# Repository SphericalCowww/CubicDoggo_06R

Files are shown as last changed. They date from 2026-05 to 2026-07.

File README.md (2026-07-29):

# Cubic Doggo 06R: Homemade 12-DOF 4-Legged Robot Recipe, With IMU

Cubic Doggo 06R High Mobility is an upgrade from the base <a href="https://github.com/SphericalCowww/CubicDoggo">Cubic Doggo</a>. It receives several mechanical improvements and applies an IMU for balance. The upgraded CADv2 files can be found in <a href="https://github.com/SphericalCowww/CubicDoggo_06R/tree/main/src/my_robot_description/mesh/CADv2">GitHub directory</a>/<a href="https://www.printables.com/model/1790901-cubic-doggo-06r-high-mobility">Printables</a>.

Demos: wobbly IMU (<a href="https://www.reddit.com/r/robotics/comments/1u1iql9/cubic_doggo_update_wobbly_imu/">Reddit</a>/<a href="https://www.reddit.com/r/ROS/comments/1u1j9yf/cubic_doggo_update_wobbly_imu/">Reddit</a>), standing IMU tunning (<a href="https://www.reddit.com/r/robotics/comments/1ugo3kj/cubic_doggo_update_returning_to_basics_after_all/">Reddit</a>/<a href="https://www.reddit.com/r/ROS/comments/1ugw66z/cubic_doggo_update_returning_to_basics_after_all/">Reddit</a>), leg lifting (<a href="https://www.reddit.com/r/robotics/comments/1ux2n51/cubic_doggo_update_what_does_it_takes_to_lift_its/">Reddit</a>), walking with IMU (<a href="https://www.reddit.com/r/robotics/comments/1v69uqf/cubic_doggo_upgrade_walking_with_imu/">Reddit</a>)



* Left: the following shows the high-lift mode available after all the mechanical improvements. The black notepad in the center is 1cm in height, and the robot is able to land on it with all 4 of its feet. However, you can see that landing off the notepad gives a rather high impact load to the landing leg.
* Right: walking with IMU balance correction based on BNO055, controlled using PID (technically on kP to avoid diverging oscillation). It's walking down from the notepad because the current IMU system cannot support the high-lift mode. Although the effect is not obvious, the robot is constantly trying to balance itself after standing up and during walking.
* Note also that a servo (or servos) from the robot's back-right leg is likely damaged/performance-reduced from dimension collisions during the test using the spring/compliant feet (see <a href="https://www.reddit.com/r/robotics/comments/1ux2n51/cubic_doggo_update_what_does_it_takes_to_lift_its/">Reddit</a>) 

## Ingredients

### CAD Improvements

1. Support on the 1st servos on both sides
2. Support on the 3rd servos. These joints always broke first
3. Spring-like feet (<a href="https://www.reddit.com/r/robotics/comments/1un8jxc/3dprinted_compliant_robot_legs/">Reddit</a>)
4. Smaller feet tip. Swinging less mass should cause less wobbling
5. Start using PLA+

Also updated the initial leg position such that the center of mass is optimized at trotting in place.

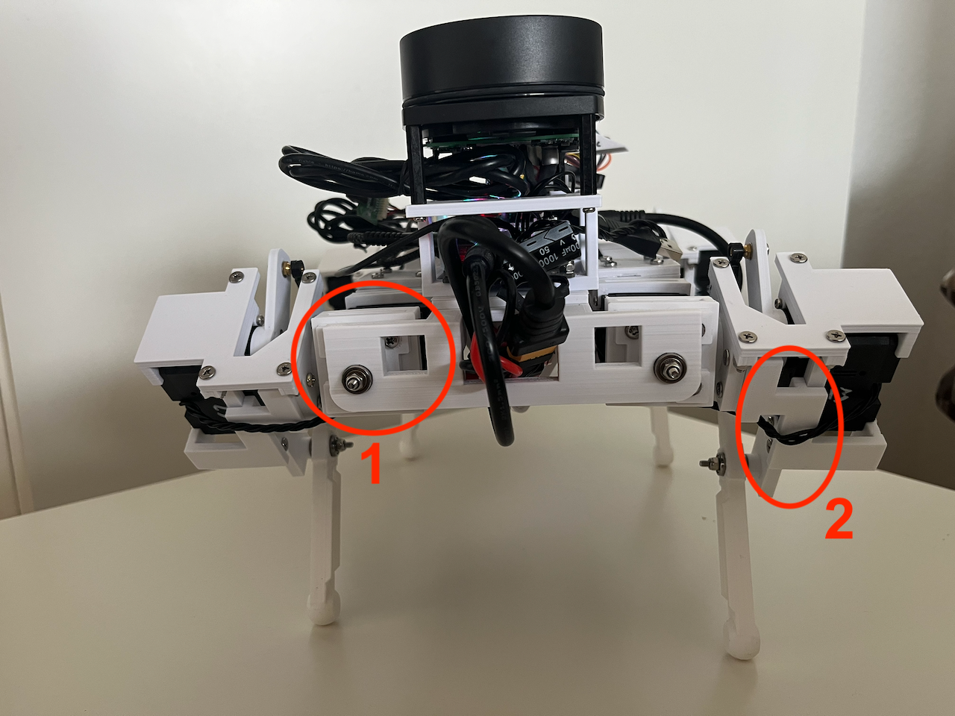
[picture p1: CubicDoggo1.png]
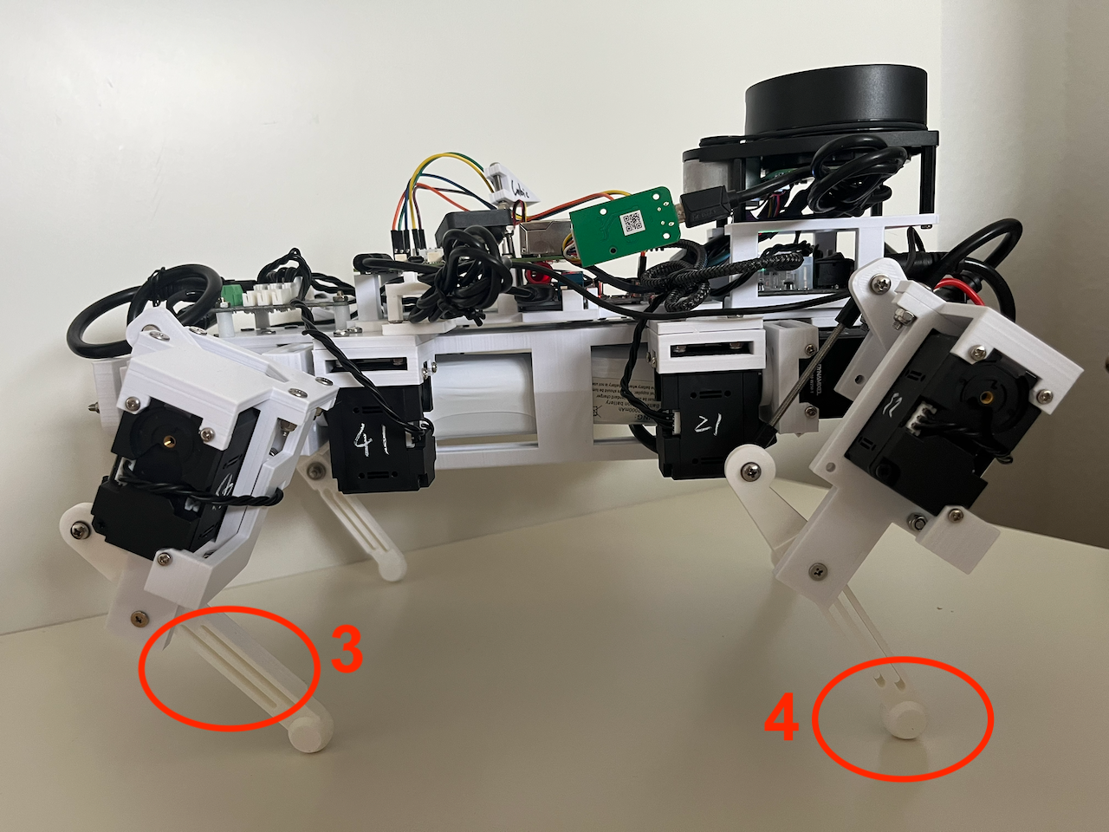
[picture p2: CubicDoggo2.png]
  

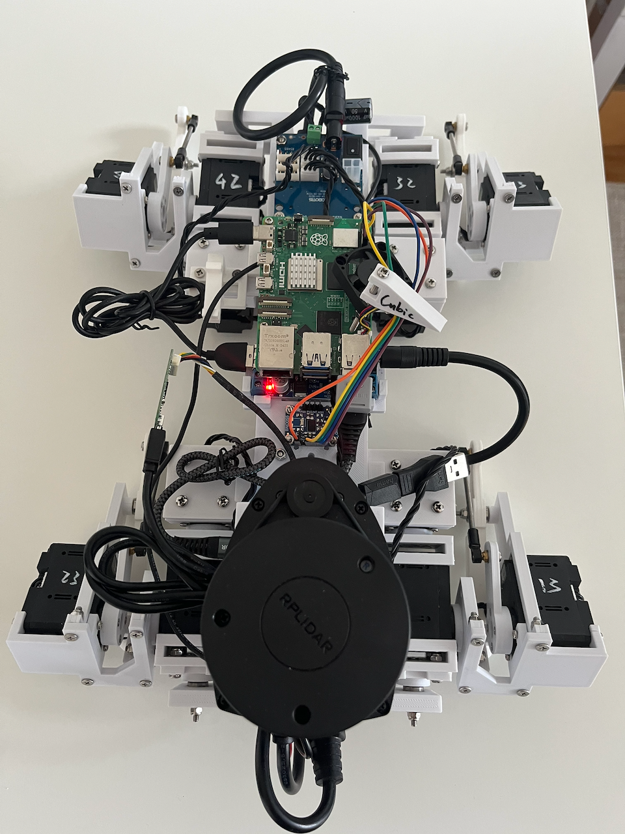
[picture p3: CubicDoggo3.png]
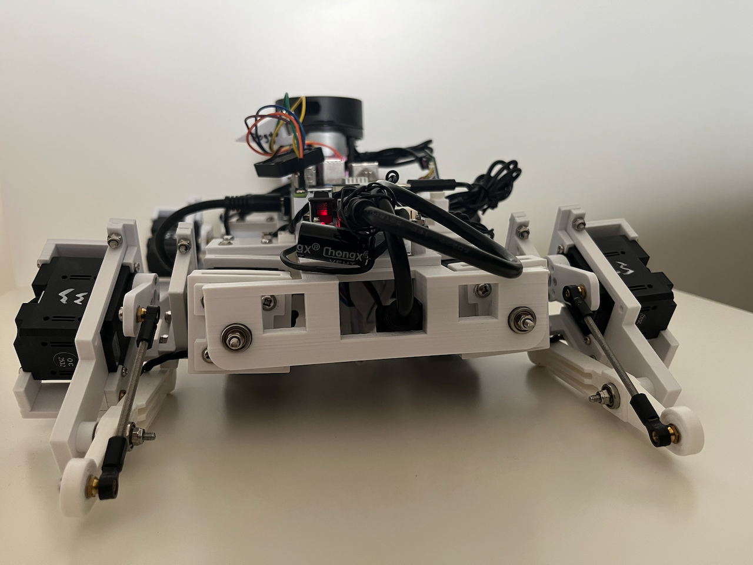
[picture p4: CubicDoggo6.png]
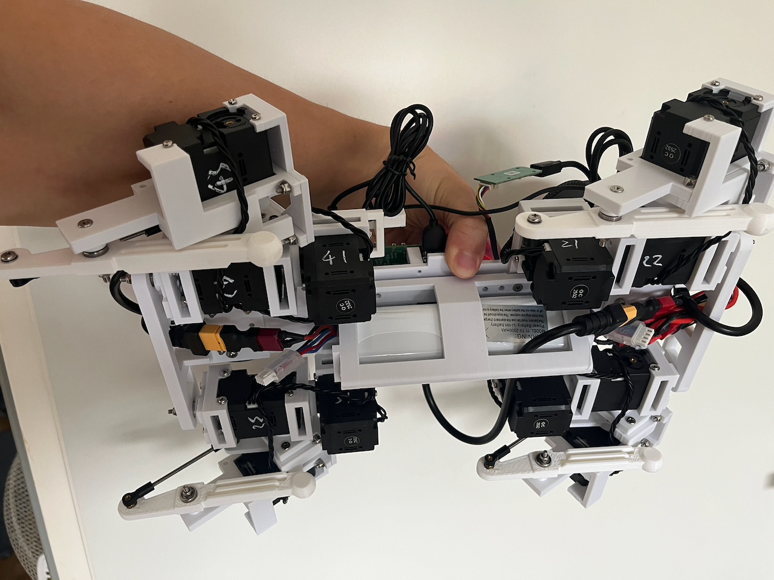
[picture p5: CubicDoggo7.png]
   

### IMU Hardware 

| device | models | count | specification |
| - | - | - | - |
| IMU | Adafruit <a href="https://www.adafruit.com/product/2472?srsltid=AfmBOopFaOJasrKIi1FkizYHaVd5CtUsoR6xX3qAALgU8sYoLY70Q55M">BNO055 [ADA2472]</a> | 1 | in-system Kalman Filter, but rate capped at 100 Hz |
| IMU | <a href="https://de.aliexpress.com/item/1005009869623539.html">BMI088</a> | 1 | rate available at 200 Hz after ROS2 ``imu_filter_madgwick`` |
| IMU | <a href="https://de.aliexpress.com/item/1005010500159119.html">ICM-42688-P</a> | 1 | rate available at 200-400 Hz after ROS2 ``imu_filter_madgwick`` |

So far, only BNO055 is tested. Future incorporation with BMI088 or ICM-42688-P will likely improve the IMU performance: the current PID oscillation is potentially caused by delayed IMU correction at the BNO055 readout rate set of 50 Hz.

## Testing IMU/Peripherals

### Testing IMU BN055

Following <a href="https://cdn-learn.adafruit.com/downloads/pdf/bno055-absolute-orientation-sensor-with-raspberry-pi-and-beaglebone-black.pdf">link</a>. It's a bit outdated, so do change up a bit and actually connect via I2C instead for RaspPi > 3:

  * Vin to 1
  * GND to 9 
  * SDA to 3
  * SCL to 5
  * RST to 11



Then do:

    sudo apt update && sudo apt install -y i2c-tools gpiod libgpiod-dev
    sudo gpiodetect
    sudo gpioset gpiochip4 17=1                                         # enable reset pin
    sudo i2cdetect -y 1                                                 # if 28 lights up, it's alive

    sudo usermod -aG i2c $USER
    sudo usermod -aG dialout $USER
    sudo reboot
    i2cdetect -y 1

To test BNO055 without ROS:
    
    sudo apt install -y python3-venv python3-pip python3-lgpio
    cd CubicDoggo_06R/python_test_scripts
    python3 -m venv env
    source env/bin/activate
    pip install adafruit-circuitpython-bno055 rpi-lgpio
    python bno_test.py
    
To test BNO055 with ROS:

    cd CubicDoggo_06R
    colcon build
    source install/setup.bash
    ros2 run my_robot_peripheral imu_bno055_node
    # on another terminal
    ros2 topic echo /imu/euler              # show IMU content
    ros2 topic hz /imu/euler                # show IMU read speed

### Testing the joystick controller:

    ls /dev/input/js*
    # output: /dev/input/js0
    # otherwise do: sudo jstest /dev/input/js0
    ros2 run joy joy_enumerate_devices
    # if no device found
    sudo usermod -aG input $USER
    sudo reboot

    cd CubicDoggo_06R
    colcon build
    source install/setup.bash
    ros2 run joy joy_node
    # on another terminal
    ros2 run my_robot_controller cubic_doggo_joy_control
    # on yet another terminal
    ros2 node info /cubic_doggo_joy_control    
    ros2 topic info /joy --verbose
    ros2 topic echo /joy

### Checking RaspPi power

    for d in /sys/class/hwmon/hwmon*; do echo -n "$d: "; cat "$d/name"; done   # find the correct path for power alarm
    # update /home/cubicdoggo/Documents/CubicDoggo_06R/src/my_robot_bringup/launch/cubic_doggo.with_lifecycle.launch.py
    echo timer | sudo tee /sys/class/leds/ACT/trigger                          # trigger LED first
    sudo chmod -R 777 /sys/class/leds/ACT/                                     # enable LED to indicate battery condition
    sudo chmod -R 777 /sys/class/hwmon/hwmon*/                                 # enable reading of power alarm/voltage
    # test the node 
    echo 0 > /tmp/fake_alarm                                                   # create a fake alarm by
    ros2 run my_robot_peripheral rasp_pi_peripheral_node --ros-args -p alarm_path:=/tmp/fake_alarm
    echo 1 > /tmp/fake_alarm                                                   # create a fake alarm by

## Running the robot

Follow this <a href="https://github.com/SphericalCowww/CubicDoggo/tree/main#running-a-single-servo-on-ros2">GitHub section</a> to set up the servos.

### Assembly and Launching URDF

Run the following to view the moving parts:

    cd CubicDoggo_06R
    colcon build
    source install/setup.bash
    ros2 launch my_robot_description cubic_doggo.rviz.launch.xacro.py

Notice that the placement of the first servo is different between the front and back legs.

### Launching with commands

Under: ``CubicDoggo_06R/src/my_robot_description/urdf/cubic_doggo.ros2_control.xacro``

   * use ``<plugin>mock_components/GenericSystem</plugin>`` if just want rViz
   * use ``<<plugin>cubic_doggo_namespace/HardwareInterfaceU2D2_cubic_doggo</plugin>`` if want to control hardware

Under: ``CubicDoggo_06R/src/my_robot_bringup/launch/cubic_doggo.with_lifecycle.launch.py``

   * choose from:
     * ``executable="cubic_doggo_lifecycle"`` for no IMU
     * ``executable="cubic_doggo_lifecycle_imuNode"`` for standing with an IMU node
     * ``executable="cubic_doggo_lifecycle_imuController"`` for standing with an IMU controller using ``ros2_control``
     * ``executable="cubic_doggo_lifecycle_imuController_walking"`` for standing/walking with an IMU controller using ``ros2_control``
     * ``executable="cubic_doggo_lifecycle_imuController_walkingToggle"`` to start with no IMU, but can toggle on for standing/walking with an IMU controller using ``ros2_control``

   * comment out ``imu_node`` unless using ``executable="cubic_doggo_lifecycle_imuNode"``
   * comment out ``rviz_node`` if don't want rViz to show
   * comment out ``joy_driver_node`` and ``joy_controller_node`` if don't want the joystick controller
   * comment out ``peripheral_node`` if don't want warning from low power

Start the robot (skip launching rviz_node, joy_driver_node, or joy_controller_node if needed):

    cd CubicDoggo_06R
    colcon build
    source install/setup.bash
    # comment in rvis node in CubicDoggo_06R/src/my_robot_bringup/launch/cubic_doggo.with_lifecycle.launch.py
    ros2 launch my_robot_bringup cubic_doggo.with_lifecycle.launch.py
    # on another terminal
    ros2 topic pub -1 /leg_set_named example_interfaces/msg/String "{data: "rest"}"
    ros2 topic pub -1 /leg_set_named example_interfaces/msg/String "{data: "stand"}"
    ros2 topic pub -1 /leg_set_named example_interfaces/msg/String "{data: "sit"}"
    ros2 topic pub -1 /leg_set_named example_interfaces/msg/String "{data: "bow"}"
    ros2 topic pub -1 /leg_set_joint example_interfaces/msg/Float64MultiArray "{data: [0, 3.14, 3.14, 3.54]}"
    ros2 topic pub -1 /leg_set_pose my_robot_interface/msg/CubicDoggoLegPoseTarget "{leg_index: 0, x: -0.092, y: 0.053, z: 0.135}" 
    ros2 service call /leg_walk_toggle std_srvs/srv/SetBool "{data: true}"
    ros2 service call /leg_walk_toggle std_srvs/srv/SetBool "{data: false}"

Check out all the gait/IMU options under ``CubicDoggo_06R/src/my_robot_commander/src/cubic_doggo_lifecycle_imuController_walking.cpp``:

    # rclcpp::get_logger("").set_level(rclcpp::Logger::Level::Warn);        // for silencing output
    ...
    # aw_strat.i_max =  0.05;
    # aw_strat.i_min = -0.05;
    # double kP = 0.0016, kI = 0.0001, kD = 0.0;     // NOTE: PID
    # double corr_v_thres = 3.0, corr_d_thres = 1.0;              // threshold on pitch/roll and their vel 
    # double corr_z_limit_kD = 0.01, corr_z_limit = 0.025;       // limit on +/- z
    # double pitch_shift = 0.643, roll_shift = -2.917;              // basic on-support reference

    # auto loop_rate = rclcpp::WallRate(update_rate_);        // Hz, for consistent loop rate
    # double maxVelScale = 1.0, maxAccScale = 1.0;
    # int    waypoint_N_walk   = 40;                         // number of waypoints for each cycle
    # double waypoint_dt_walk  = 0.5/double(update_rate_);    // second for each waypoint, to match loop rate
    # int    waypoint_N_stand  = 1;                           // standing require immidiate reaction
    # double waypoint_dt_stand = 1.0/double(update_rate_);    // standing require faster trajectory
    # double IK_bufferTime     = 0.10;                        // time at end of cycle buffer for IK calc
    # double swing_fraction    = 0.32;                        // creep < 0.25 < stable trot < 0.5 < trot
    # double lift = 0.02, x_stride_max = 0.02, y_stride_max = 0.03, x_shift = 0.0, y_shift = -0.007;

### Launching at the start of RaspPi

    chmod +x /home/cubicdoggo/Documents/CubicDoggo_06R/start_robot.sh
    sudo cp /home/cubicdoggo/Documents/CubicDoggo_06R/robot_startup.service /etc/systemd/system/robot_startup.service
    sudo chmod 644 /etc/systemd/system/robot_startup.service
    sudo systemctl enable robot_startup.service                                # now will start at reboot
    sudo systemctl daemon-reload                                               # reload whenever there is a change
    # sudo systemctl restart robot_startup.service                             # restart, even if is rrunning
    # sudo systemctl stop    robot_startup.service                             # stop right now, kill all relevant nodes
    # sudo systemctl disable robot_startup.service                             # disable at reboot
    # journalctl -u robot_startup.service -n 100 > start_robot_output.txt      # to check the output
    # journalctl -u robot_startup.service -f

## Tracking the variables

Run the robot first:

    cd CubicDoggo_06R
    colcon build
    source install/setup.bash
    ros2 launch my_robot_bringup cubic_doggo.with_lifecycle.launch.py

### Reading out variables from ROS

    # on another terminal for joint states
    ros2 topic echo /joint_states
    # on another terminal for IMU
    ros2 topic echo /imu/euler

### Tracking/plotting variables using PlotJuggler

To track the values (remember to connect the RaspPi to a monitor):

    # on another terminal for plotjuggler
    sudo apt install ros-jazzy-plotjuggler-ros
    ros2 run plotjuggler plotjuggler
    # load CubicDoggo_06R/monitor_plot.xml 
    # or starting over again:
    ## start => locate the following
    ### /imu/data
    ### /imu/euler
    ### /joint_states
    ## OK
    ## on the left panel, expand /imu and /joint_states and drag the variable to the center for live plotting

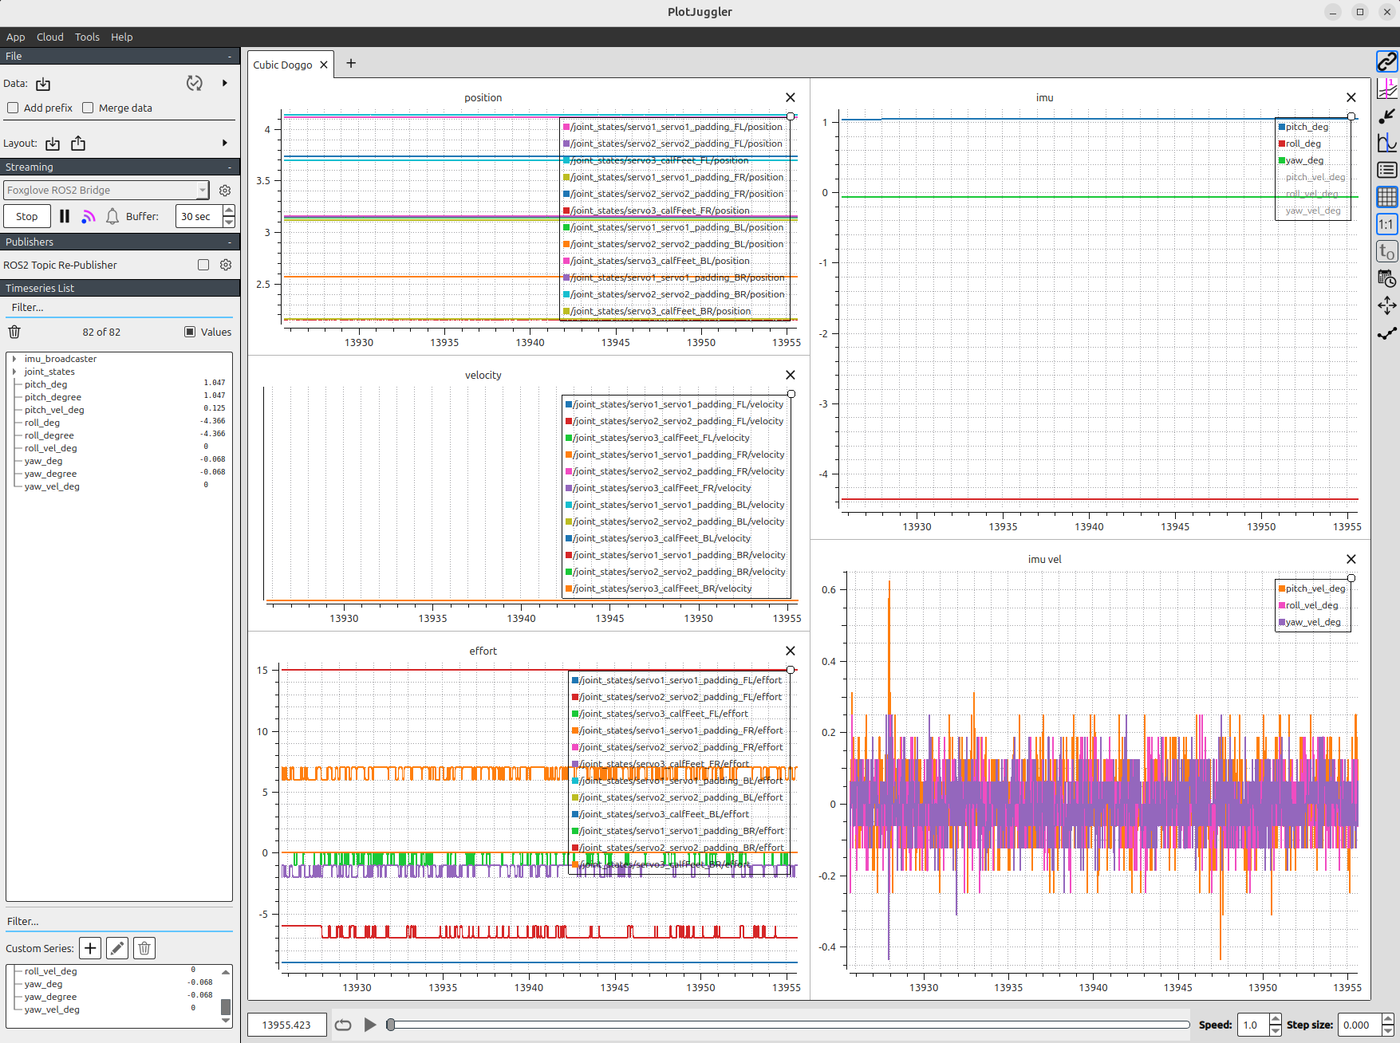
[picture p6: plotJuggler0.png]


Note that to enable plotting, the robot needs an HDMI cable to connect to the monitor, a mouse, a keyboard, and a direct power source (it's rather energy-consuming). The controller is still remote. This means extra weights are placed on the robot, and so what's being plotted is not exactly equivalent to battery mode. The photo shows the connections:

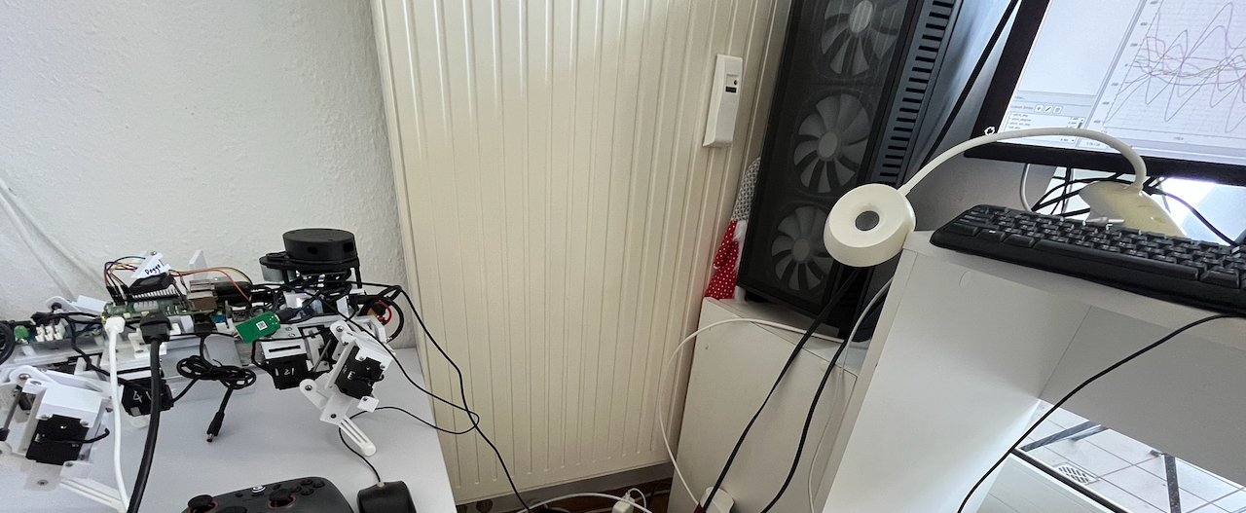
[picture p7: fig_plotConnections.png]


### IMU balancing

Configuration (update the code if direction differs):

    roll, negative when tilting forward
    pitch, negative when tilting leftward

Checking loop speed for latency, including IK calculation and IMU readout:

    ros2 topic hz /joint_states

Standing up and then changing to a slope, with Kp parameter only. Never correct to the exact values:

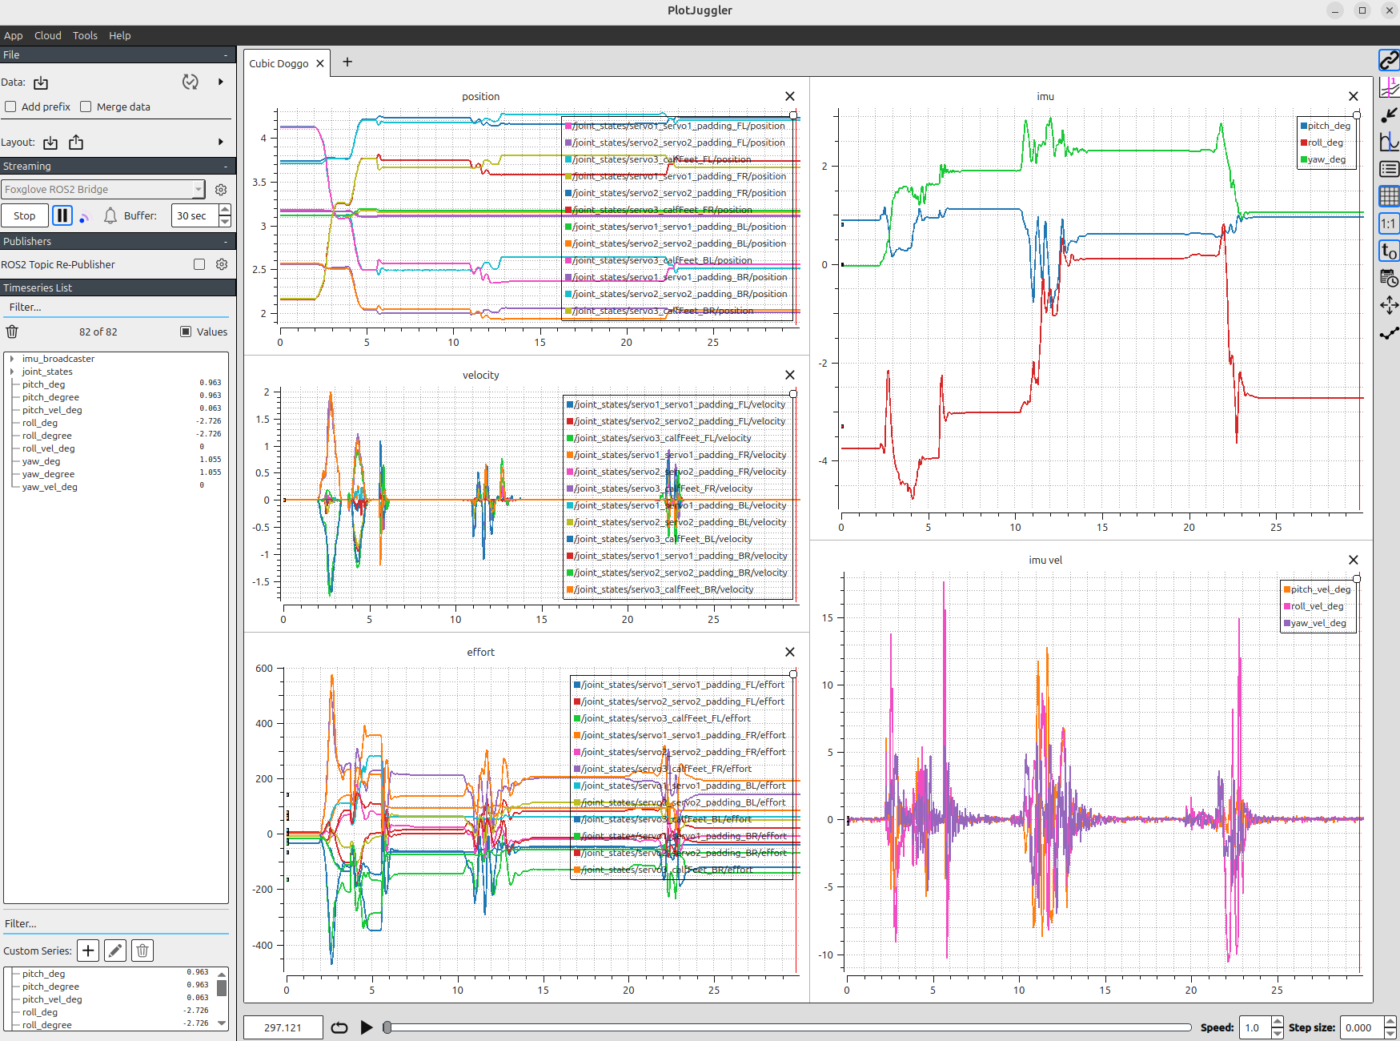
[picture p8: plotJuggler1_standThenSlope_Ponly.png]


Standing up and then changing to a slope, with full PID parameters. Large oscillations:

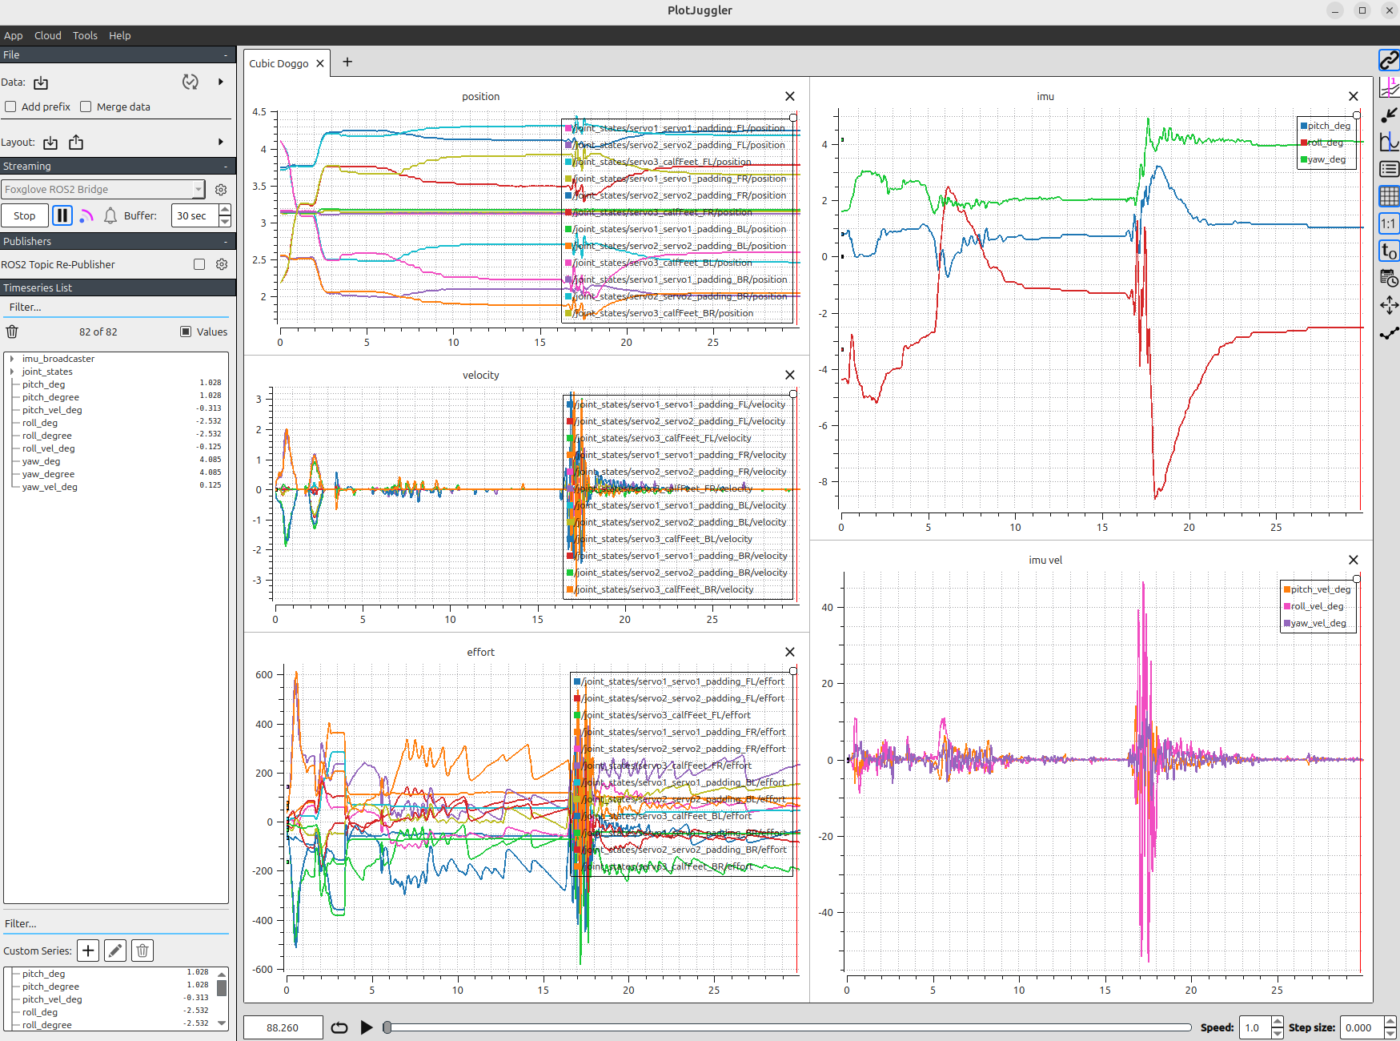
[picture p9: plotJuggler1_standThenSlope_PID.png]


### Walking gaits

Walking gait, trotting in place:

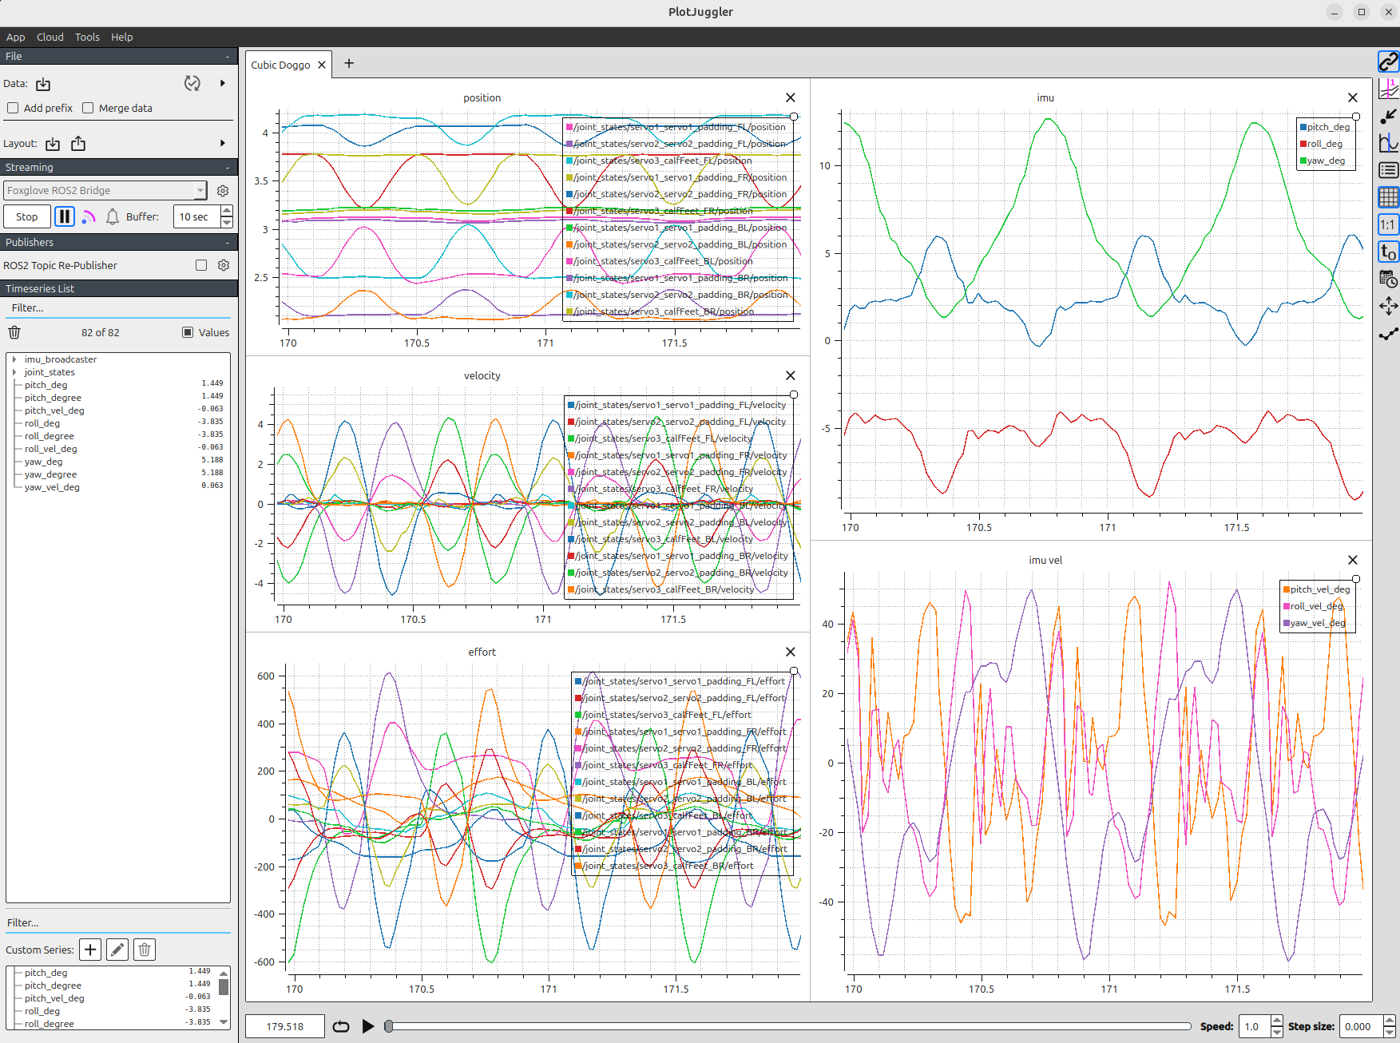
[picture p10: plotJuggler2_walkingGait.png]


Walking gait with IMU, trotting in place:

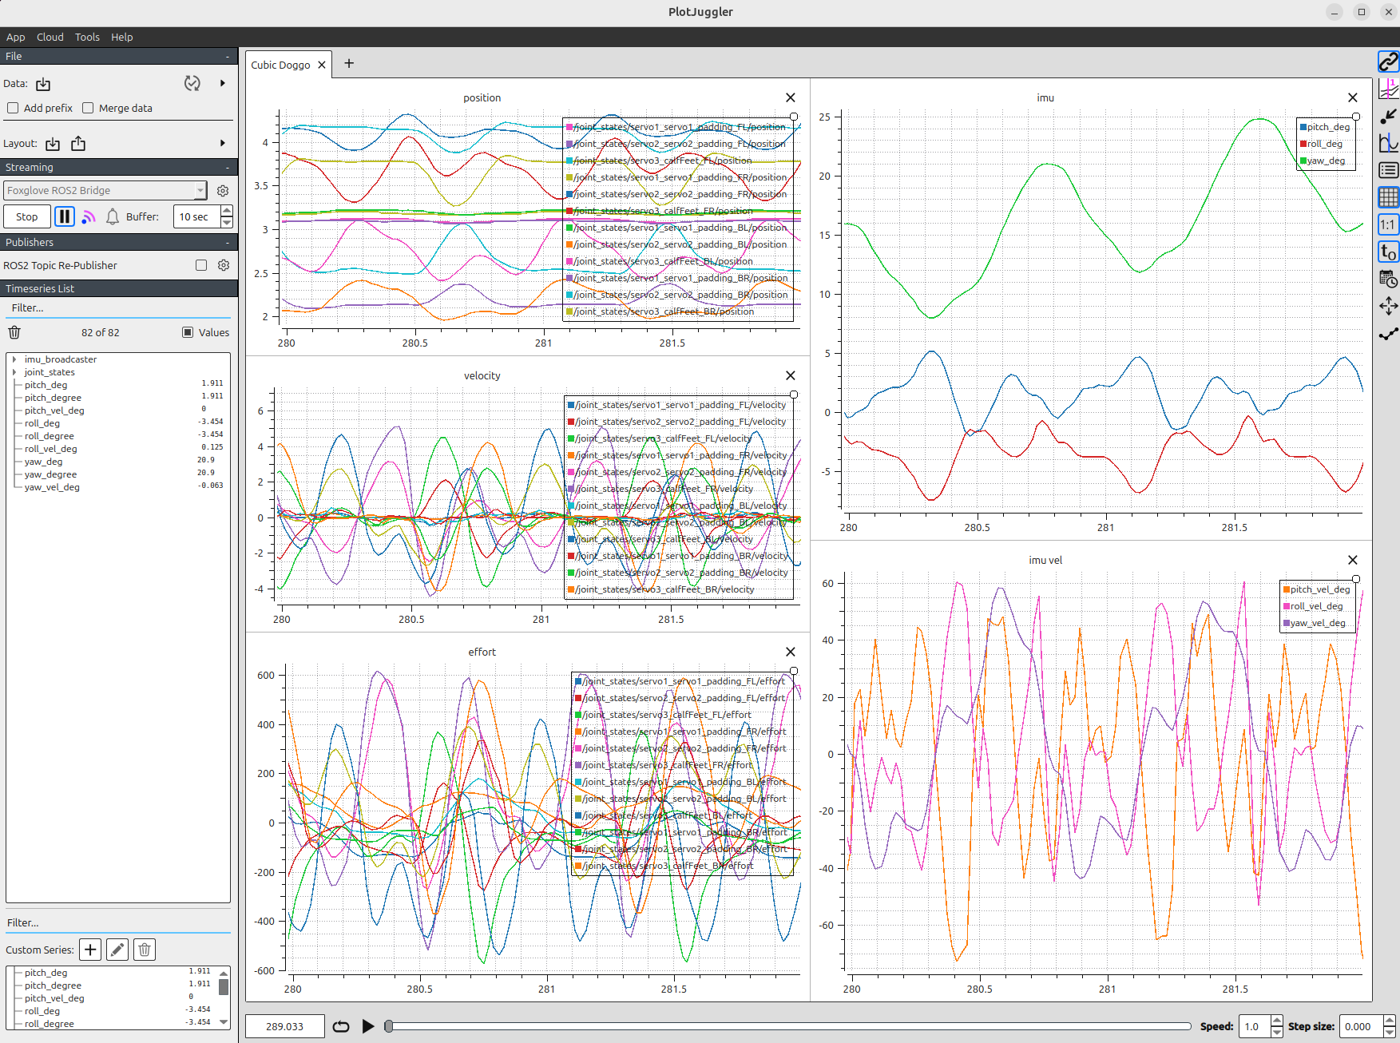
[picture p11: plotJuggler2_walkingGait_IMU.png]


High-lift walking gait, trotting in place:

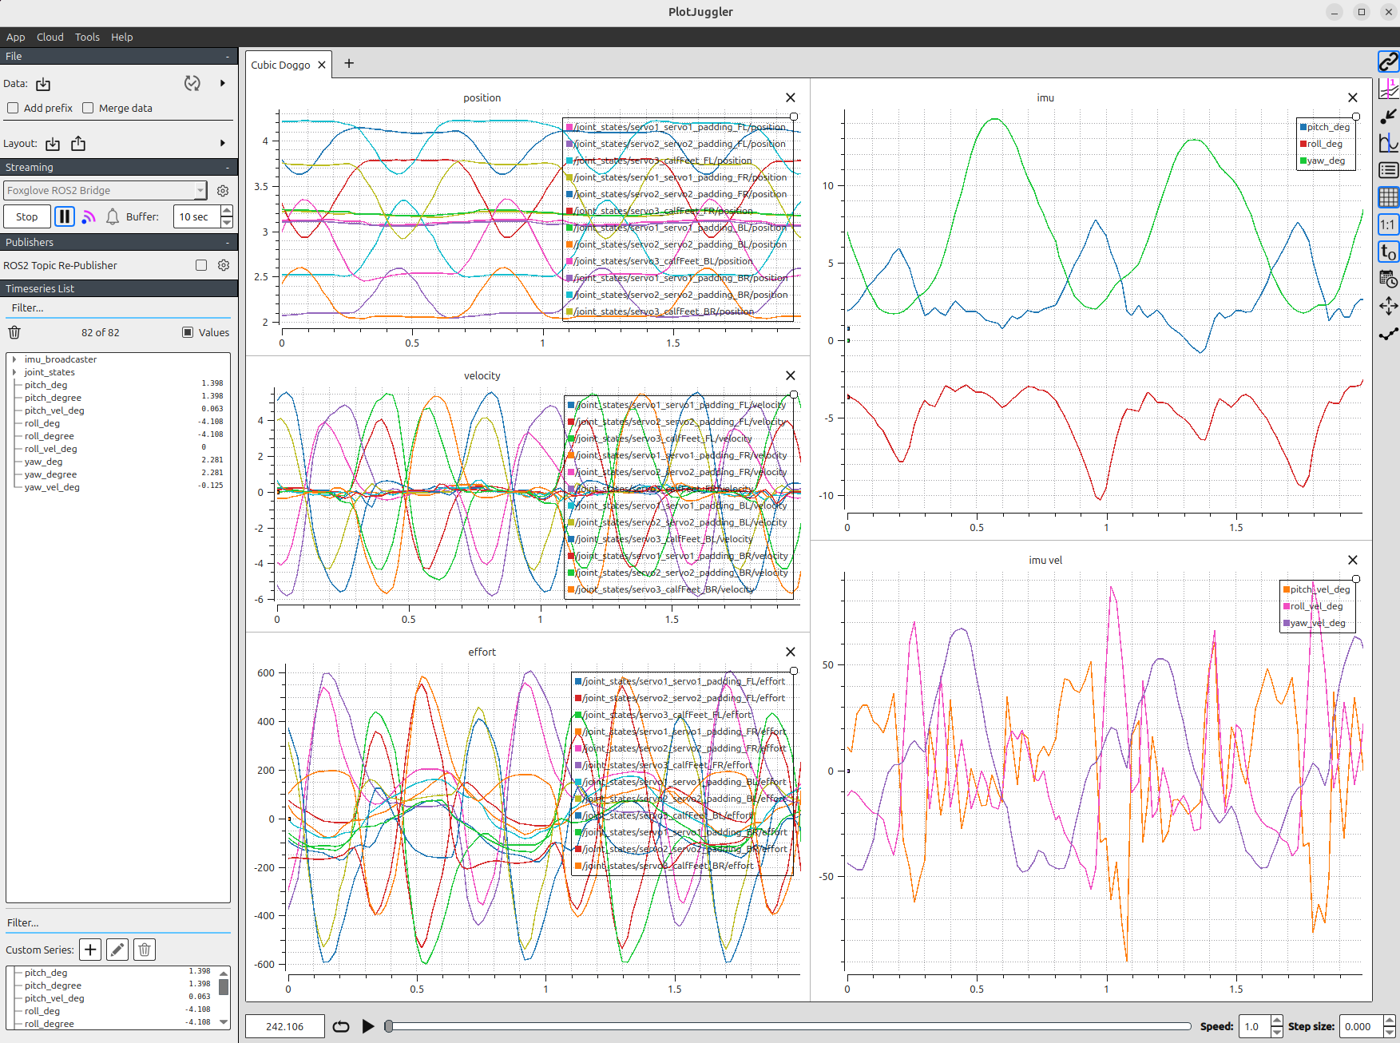
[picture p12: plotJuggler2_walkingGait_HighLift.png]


## Next directions

- <a href="https://github.com/SphericalCowww/CubicDoggo_07B">Cubic Doggo 07B Wouf</a>: ST-3215-C018 servo adaptation (higher torque, cheaper, but harder to develop)
- <a href="https://github.com/SphericalCowww/CubicDoggo_06Z">Cubic Doggo 06Z Neucommu</a>: AI and simulation testbed for reinforcement learning

## References:

- Dr Jon EA: Pico & Pico 2, The BNO055: At Last, an IMU I Can Tame Quickly - C/C++ (<a href="https://www.youtube.com/watch?v=x6I02YAyZmU">YouTube</a>) 
- ROS1 Packages for CHAMP Quadruped Controller (<a href="https://github.com/chvmp/champ">GitHub</a>) => node based IMU control with classical walk gait
- Spot Micro (<a href="https://github.com/mike4192/spotMicro">GitHub</a>, <a href="https://spotmicroai.readthedocs.io/en/latest/">link</a>) => node based IMU control with classical walk gait
- Pupper V3 (<a href="https://pupper-v3-documentation.readthedocs.io/en/latest/">link</a>) => ros2_control based IMU control with RL walk gait

## Acknowledgements

- Some utility programs are adapted from the ROBOTIS DYNAMIXEL Workbench examples: https://github.com/ROBOTIS-GIT/dynamixel-workbench/tree/main/dynamixel_workbench_toolbox/examples/src. These files remain licensed under the Apache License 2.0. Modifications are documented in the source files.

- Thanks to all the Redditors for their nice comments/advices :)

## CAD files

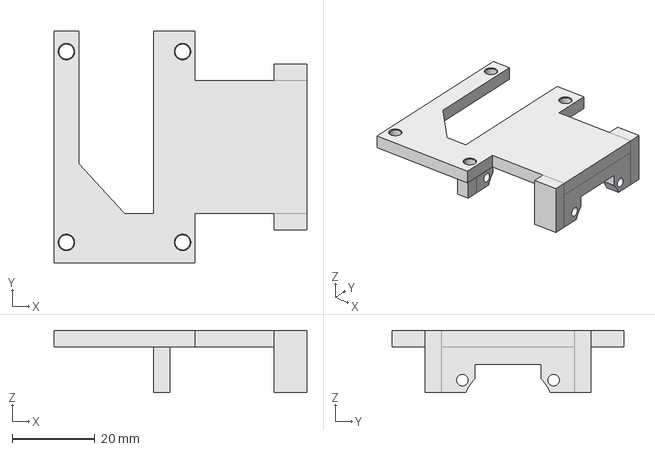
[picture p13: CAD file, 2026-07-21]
src/my_robot_description/mesh/CADv2/XL430holderThighFront.FCStd
61.0 x 56.0 x 15.0 mm

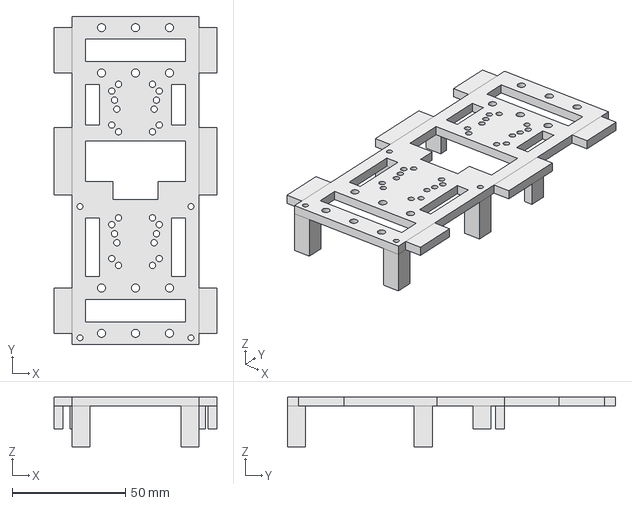
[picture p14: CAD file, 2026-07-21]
src/my_robot_description/mesh/CADv2/baseTorso.FCStd
72.0 x 145.0 x 22.0 mm

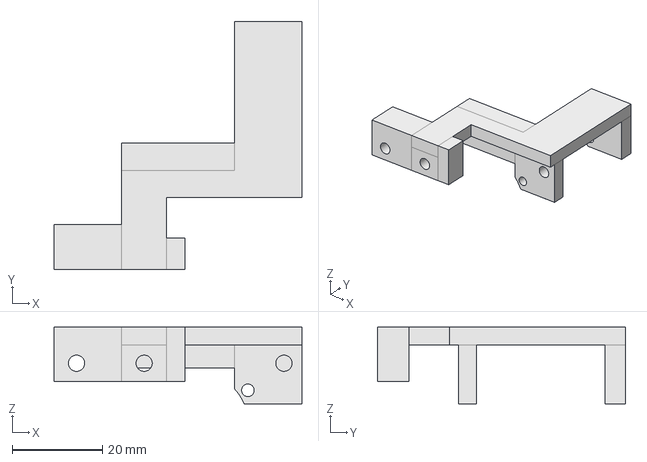
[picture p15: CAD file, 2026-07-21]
src/my_robot_description/mesh/CADv2/XL430holderThighBack.FCStd
55.0 x 55.0 x 17.0 mm

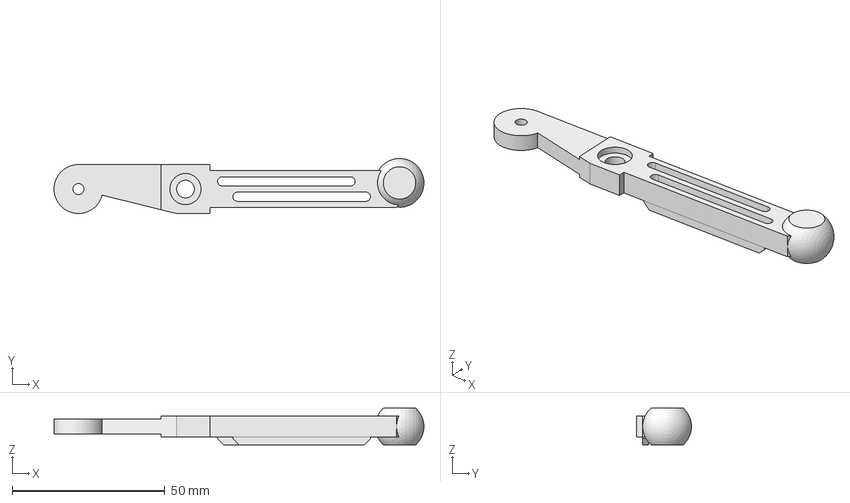
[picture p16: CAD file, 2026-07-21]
src/my_robot_description/mesh/CADv2/calfFeetSpring.FCStd
121.0 x 18.0 x 12.0 mm

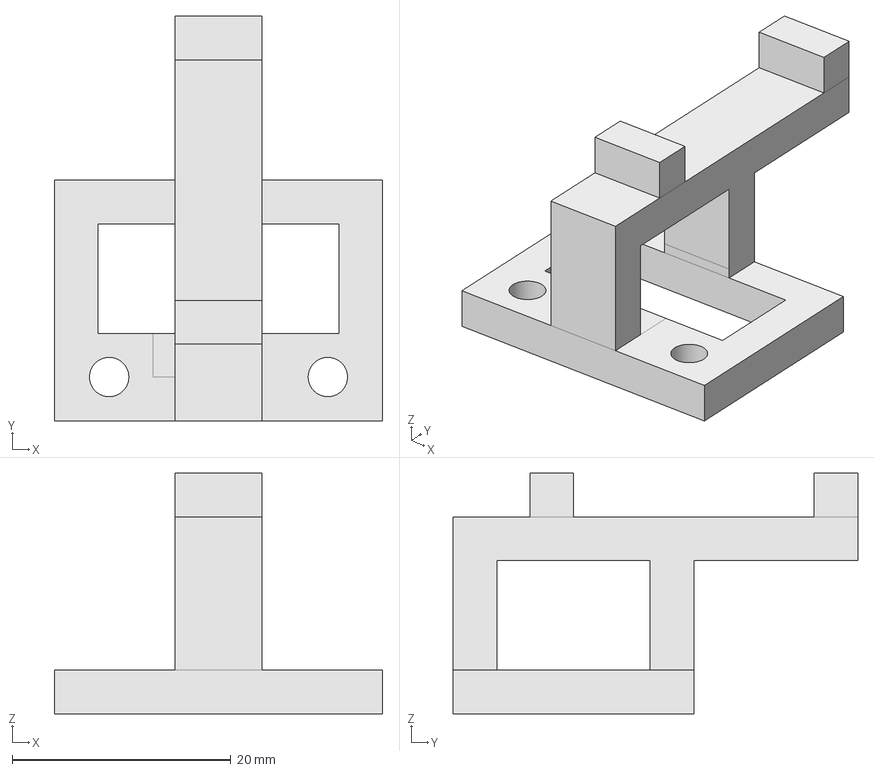
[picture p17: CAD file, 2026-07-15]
src/my_robot_description/mesh/CADv2/hdmiHolder.FCStd
30.0 x 37.0 x 22.0 mm

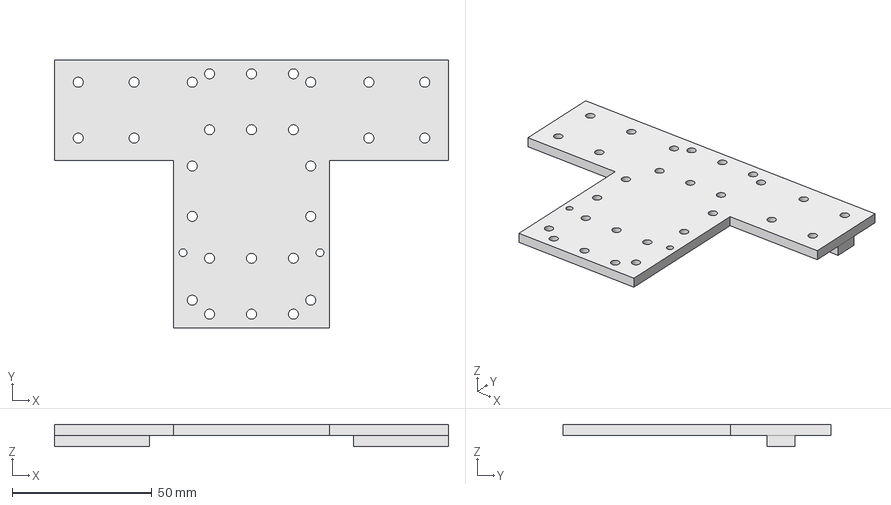
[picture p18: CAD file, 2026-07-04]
src/my_robot_description/mesh/CADv2/basePlate.FCStd
141.0 x 96.0 x 8.00 mm

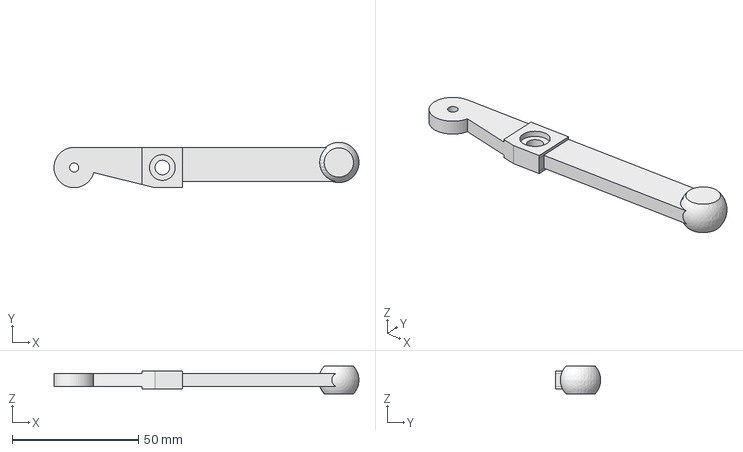
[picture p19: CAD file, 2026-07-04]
src/my_robot_description/mesh/CADv2/calfFeet.FCStd
121.0 x 18.0 x 11.0 mm

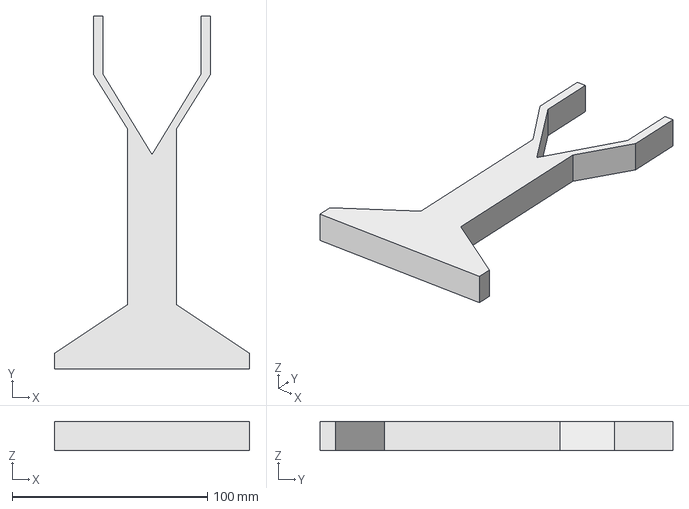
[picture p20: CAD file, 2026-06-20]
src/my_robot_description/mesh/CADv2/bodyHolder.FCStd
100.0 x 181.0 x 15.0 mm

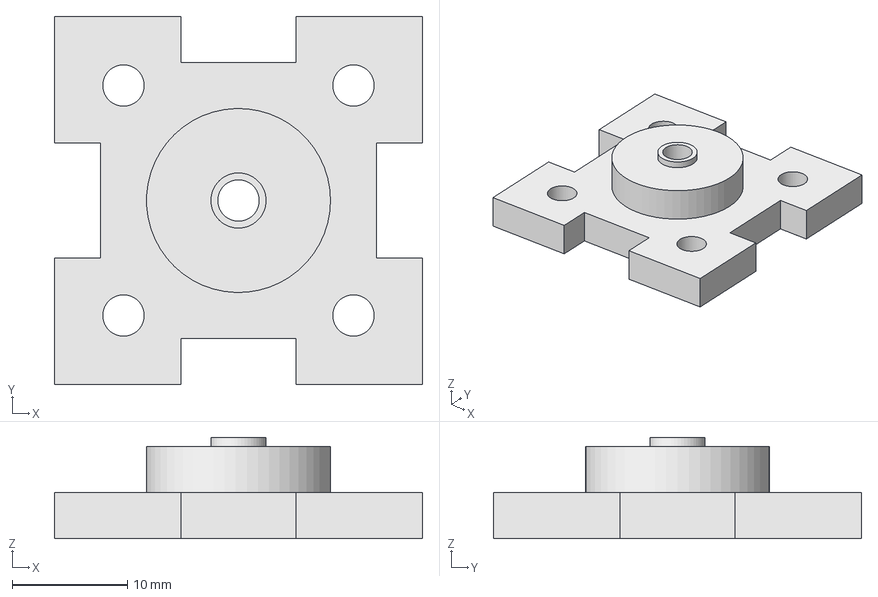
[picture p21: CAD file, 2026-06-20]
src/my_robot_description/mesh/CADv2/bearingPadding.FCStd
32.0 x 32.0 x 8.80 mm

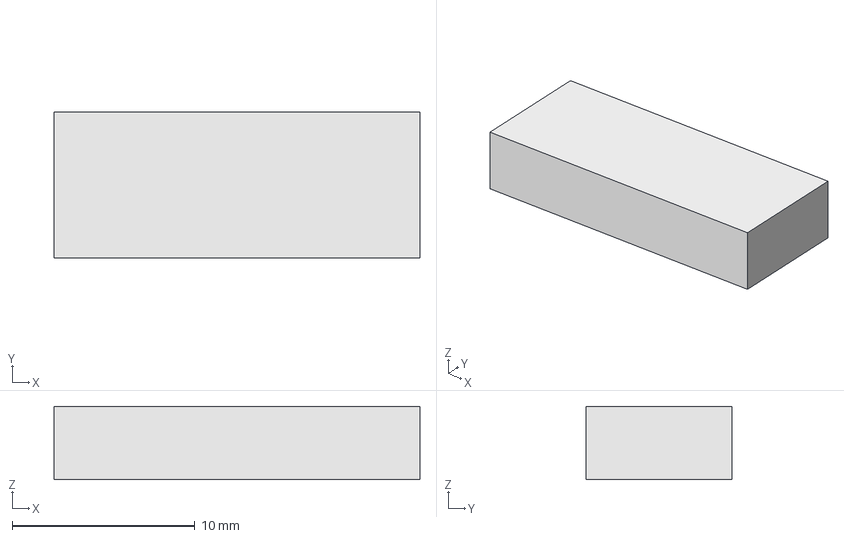
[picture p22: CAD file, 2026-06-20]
src/my_robot_description/mesh/CADv2/baseSticker.FCStd
20.0 x 8.00 x 4.00 mm

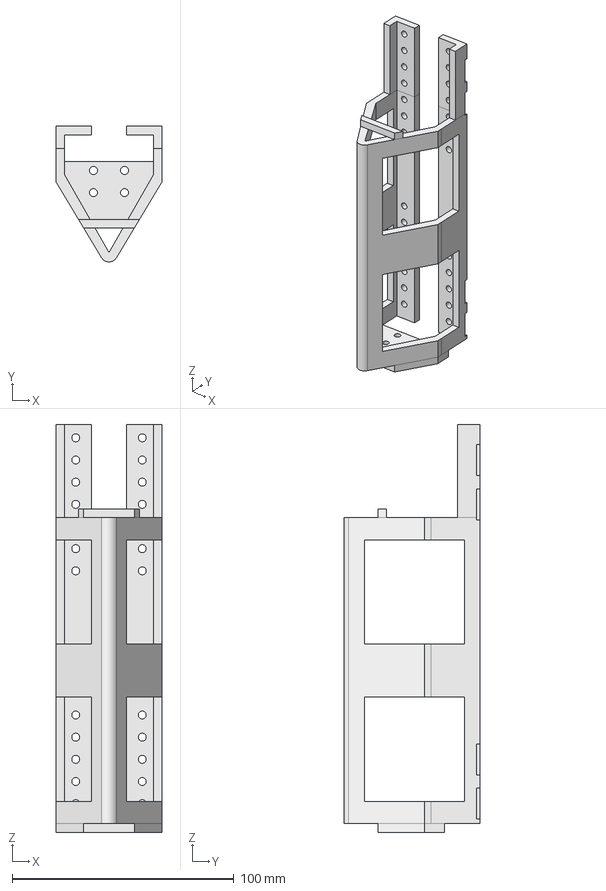
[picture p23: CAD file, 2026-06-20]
src/my_robot_description/mesh/CADv2/batteryHolder.FCStd
48.0 x 61.2 x 184.0 mm

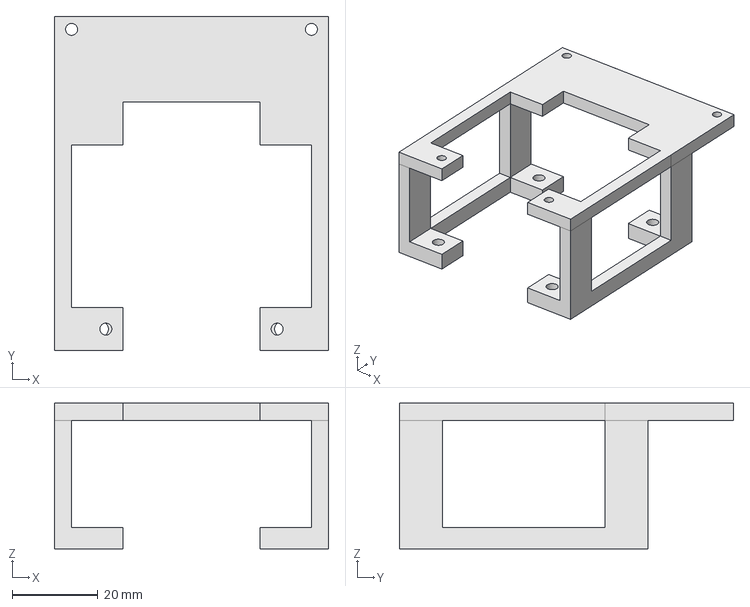
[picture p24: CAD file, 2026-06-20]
src/my_robot_description/mesh/CADv2/lidarHolder.FCStd
64.0 x 78.0 x 34.0 mm

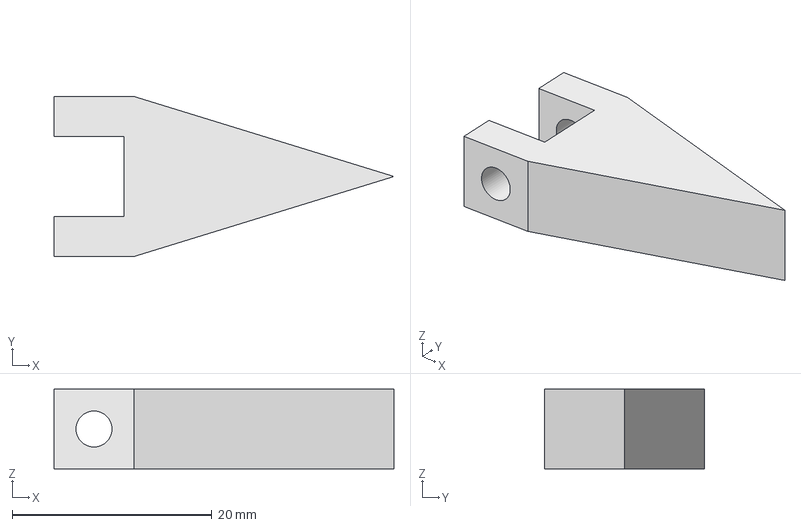
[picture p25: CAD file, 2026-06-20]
src/my_robot_description/mesh/CADv2/fanFlag.FCStd
34.0 x 16.0 x 8.00 mm

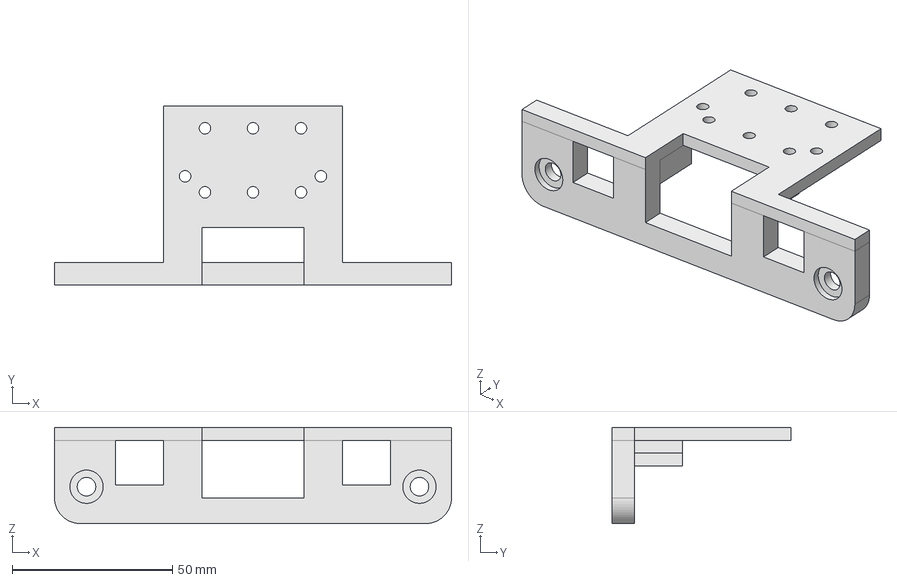
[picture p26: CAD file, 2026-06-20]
src/my_robot_description/mesh/CADv2/bearingPlate.FCStd
124.0 x 56.0 x 30.0 mm

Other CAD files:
src/my_robot_description/mesh/CADv2/thighInner.FCStd
src/my_robot_description/mesh/CADv2/XL430rotorPadding.FCStd
src/my_robot_description/mesh/CADv2/calfJoint.FCStd
src/my_robot_description/mesh/CADv2/thighOuter.FCStd
src/my_robot_description/mesh/CADv2/XL430holderBasic.FCStd
src/my_robot_description/mesh/CADv2/XL430holderBasic.stl
src/my_robot_description/mesh/CADv2/XL430rotorPadding.stl
src/my_robot_description/mesh/CADv2/basePlate.stl
src/my_robot_description/mesh/CADv2/baseTorso.stl
src/my_robot_description/mesh/CADv2/bodyHolderWide.FCStd
src/my_robot_description/mesh/CADv2/calfFeet.stl
src/my_robot_description/mesh/CADv2/calfFeetSpring.stl
src/my_robot_description/mesh/CADv2/calfJoint.stl
src/my_robot_description/mesh/CADv2/thighInner.stl
src/my_robot_description/mesh/CADv2/thighOuter.stl

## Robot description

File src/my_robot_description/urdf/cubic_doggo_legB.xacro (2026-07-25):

<?xml version="1.0"?>
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
<robot xmlns:xacro="http://www.ros.org/wiki/xacro">
    <xacro:macro name="doggo_legB" params="prefix">

    <xacro:property name="servo_x" value="0.0285"/>
    <xacro:property name="servo_y" value="0.0465"/>
    <xacro:property name="servo_z" value="0.034"/>
    <xacro:if value="${prefix == 'BL'}">
        <xacro:property name="rflc" value="-1"/>
        <xacro:property name="base_plate" value='base_plate_B'/>
        <xacro:property name="servo1_holder_xyz" value=" 0.052 0.018 0.004"/>
    </xacro:if>
    <xacro:if value="${prefix == 'BR'}">
        <xacro:property name="rflc" value=" 1"/>
        <xacro:property name="base_plate" value='base_plate_B'/>
        <xacro:property name="servo1_holder_xyz" value="-0.052 0.018 0.004"/>
    </xacro:if> 
    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
    <link name="servo1_holder_${prefix}">
        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
        <xacro:box_inertia m="0.0098" x="0.037" y="0.037" z="0.014" o_xyz="0 0 0.007" o_rpy="0 0 ${urdf_pi/2}"/>
    </link> 
    <joint name="base_plate_servo1_holder_${prefix}" type="fixed">
        <parent link="${base_plate}"/>
        <child link="servo1_holder_${prefix}"/>
        <origin xyz="${servo1_holder_xyz}" rpy="0 0 0"/>
    </joint>
    
    <link name="servo1_${prefix}">
        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
        <xacro:box_inertia m="0.0572" x="${servo_x}" y="${servo_y}" z="${servo_z}" o_xyz="0 0 ${servo_y/2}" o_rpy="${urdf_pi/2} 0 0"/>
    </link> 
    <joint name="servo1_holder_servo1_${prefix}" type="fixed">
        <parent link="servo1_holder_${prefix}"/>
        <child link="servo1_${prefix}"/>
        <origin xyz="0 0 0.008" rpy="0 0 0"/>
    </joint>

    <link name="servo1_padding_${prefix}">
        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
        <xacro:cylinder_inertia m="0.0013" r="0.011" l="0.004" o_xyz="0 -0.002 0" o_rpy="${urdf_pi/2} 0 0"/>
    </link> 
    <joint name="servo1_servo1_padding_${prefix}" type="revolute">
        <parent link="servo1_${prefix}"/>
        <child link="servo1_padding_${prefix}"/>
        <origin xyz="0 ${-servo_z/2-0.002} ${0.01+0.0025/2}" rpy="0 0 0"/>
        <axis xyz="0 -1 0"/>
        <limit effort="1000.0" velocity="50.0" lower="${urdf_pi - urdf_pi/3}" upper="${urdf_pi + urdf_pi/3}"/>
        <dynamics friction="0.05" damping="0.1"/>
    </joint>

    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
    <link name="servo2_holder_${prefix}">
        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
        <xacro:box_inertia m="0.0098" x="0.037" y="0.037" z="0.014" o_xyz="0 -0.007 0" o_rpy="${urdf_pi/2} 0 0"/>
    </link> 
    <joint name="base_link_servo2_holder_${prefix}" type="fixed">
        <parent link="servo1_padding_${prefix}"/>
        <child link="servo2_holder_${prefix}"/>
        <origin xyz="0 -0.004 0" rpy="0 0 0"/>
    </joint>
    
    <link name="servo2_${prefix}">
        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
        <xacro:box_inertia m="0.0572" x="${servo_x}" y="${servo_y}" z="${servo_z}" o_xyz="0 ${-servo_y/2} 0" o_rpy="0 ${rflc*urdf_pi/2} 0"/>
    </link> 
    <joint name="servo2_holder_servo2_${prefix}" type="fixed">
        <parent link="servo2_holder_${prefix}"/>
        <child link="servo2_${prefix}"/>
        <origin xyz="0 -0.008 0" rpy="0 0 0"/>
    </joint>

    <link name="servo2_padding_${prefix}">
        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
        <xacro:cylinder_inertia m="0.0013" r="0.011" l="0.004" o_xyz="${rflc*0.002} 0 0" o_rpy="0 ${urdf_pi/2} 0"/>
    </link> 
    <joint name="servo2_servo2_padding_${prefix}" type="revolute">
        <parent link="servo2_${prefix}"/>
        <child link="servo2_padding_${prefix}"/>
        <origin xyz="${rflc*(servo_z/2+0.002)} -0.01125 0" rpy="0 0 0"/>
        <axis xyz="${rflc} 0 0"/>
        <limit effort="1000.0" velocity="50.0" lower="${urdf_pi - 2*urdf_pi/6 + rflc*urdf_pi/6}" upper="${urdf_pi + 2*urdf_pi/6 + rflc*urdf_pi/6}"/>
        <dynamics friction="0.05" damping="0.1"/>
    </joint>

    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
    <link name="inner_thigh_${prefix}">
        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
        <xacro:box_inertia m="0.0085" x="0.032" y="0.040" z="0.006" o_xyz="${rflc*0.003} -0.016 0" o_rpy="${rflc*urdf_pi/2} 0 ${urdf_pi/2}"/>
    </link>
    <joint name="servo2_padding_inner_thigh_${prefix}" type="fixed">
        <parent link="servo2_padding_${prefix}"/>
        <child link="inner_thigh_${prefix}"/>
        <origin xyz="${rflc*0.004} -0.016 0" rpy="0 0 0"/>
    </joint>

    <link name="outer_thigh_${prefix}">
        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
        <xacro:box_inertia m="0.0113" x="0.040" y="0.032" z="0.006" o_xyz="${rflc*0.003} 0.0475 0" o_rpy="${-urdf_pi/2} ${urdf_pi/2-rflc*urdf_pi/2} ${-rflc*urdf_pi/2}"/>
    </link>
    <joint name="inner_thigh_outer_thigh_${prefix}" type="fixed">
        <parent link="inner_thigh_${prefix}"/>
        <child link="outer_thigh_${prefix}"/>
        <origin xyz="${rflc*0.028} 0 0" rpy="${urdf_pi} 0 0"/>
    </joint>

    <link name="servo3_${prefix}">
        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
        <xacro:box_inertia m="${0.0572+0.0113+0.0078}" x="${servo_x}" y="${servo_y}" z="${servo_z}" o_xyz="0 ${-servo_y/2} 0" o_rpy="0 ${rflc*urdf_pi/2} 0"/>
    </link>
    <joint name="outer_thigh_servo3_${prefix}" type="fixed">
        <parent link="outer_thigh_${prefix}"/>
        <child link="servo3_${prefix}"/>
        <origin xyz="${rflc*(servo_y/2-0.006-0.0025)} -0.004 0" rpy="0 0 0"/>
    </joint>

    <link name="calfFeet_${prefix}">
        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
        <xacro:box_inertia m="${0.0251-0.0080}" x="0.110" y="0.016" z="0.004" o_xyz="0 ${-0.008+0.008} ${0.035-0.050}" o_rpy="0 ${-urdf_pi/2} 0"/>
    </link>
    <joint name="servo3_calfFeet_${prefix}" type="revolute">
        <parent link="servo3_${prefix}"/>
        <child link="calfFeet_${prefix}"/>
        <origin xyz="${rflc*(-servo_z/2-0.002-0.0025)} ${-0.086+0.004} 0" rpy="${urdf_pi} 0 0"/>
        <axis xyz="${-rflc} 0 0"/>
        <limit effort="1000.0" velocity="50.0" lower="${5*urdf_pi/8}" upper="${11*urdf_pi/8}"/>
        <dynamics friction="0.0128" damping="0.1"/>
    </joint>

    <link name="calfJoint_${prefix}">
        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
        <xacro:box_inertia m="${0.0047+0.0015}" x="0.022" y="0.053" z="0.007" o_xyz="${-rflc*0.0005} 0 -0.0155" o_rpy="${-urdf_pi/2} 0 ${-rflc*urdf_pi/2}"/>
    </link>
    <joint name="servo3_calfJoint_${prefix}" type="revolute">
        <parent link="servo3_${prefix}"/>
        <child link="calfJoint_${prefix}"/>
        <origin xyz="${rflc*(-servo_z/2-0.002-0.0025)} ${-0.01-0.0025/2} 0" rpy="0 0 0"/>
        <axis xyz="${-rflc} 0 0"/>
        <mimic joint="servo3_calfFeet_${prefix}" multiplier="1.0" offset="0.0"/>
        <limit effort="1000.0" velocity="50.0" lower="${5*urdf_pi/8}" upper="${11*urdf_pi/8}"/>
        <dynamics friction="0.0212" damping="0.1"/>
    </joint>

    <link name="calfSphere_${prefix}">
        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
        <xacro:sphere_inertia m="0.0080" r="0.011" o_xyz="0 0 0" o_rpy="0 0 0"/>
    </link>
    <joint name="calfFeet_calfSphere_${prefix}" type="fixed">
        <parent link="calfFeet_${prefix}"/>
        <child link="calfSphere_${prefix}"/>
        <origin xyz="0 -0.004 ${-0.105+0.035}" rpy="0 0 0"/>
    </joint>
    </xacro:macro>
</robot>
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

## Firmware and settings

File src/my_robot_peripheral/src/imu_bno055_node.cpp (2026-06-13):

#include <rclcpp/rclcpp.hpp>
#include <geometry_msgs/msg/vector3.hpp>
#include <sensor_msgs/msg/imu.hpp>
#include <fcntl.h>
#include <sys/ioctl.h>
#include <linux/i2c-dev.h>
#include <unistd.h>
#include <fstream>
#include <string>
#include <chrono>
#include <filesystem> 
#include <thread>
#include <cmath> 

//////////////////////////////////////////////////////////////////////////////////////////////////////////////////////
class IMUBNO055Node : public rclcpp::Node {
public:
    IMUBNO055Node() : Node("bno055_node") {
        this->declare_parameter("i2c_bus",   "/dev/i2c-1");
        this->declare_parameter("address",   0x28);
        this->declare_parameter("reset_pin", "17");

        if (setup_hardware() == true) {
            RCLCPP_INFO(get_logger(), "IMUBNO055Node(): Connection established and sensor initialized.");
            imu_pub_   = this->create_publisher<sensor_msgs::msg::Imu>(      "imu/data",  10);
            euler_pub_ = this->create_publisher<geometry_msgs::msg::Vector3>("imu/euler", 10);
            timer_ = this->create_wall_timer(
                std::chrono::milliseconds(10),                                                          // 100 Hz 
                std::bind(&IMUBNO055Node::read_and_publish, this)
            );
        }
    }
    ~IMUBNO055Node() {
        if (i2c_fd_ >= 0) close(i2c_fd_);
    }
//////////////////////////////////////////////////////////////////////////////////////////////////////////////////////
private:
    bool setup_hardware() {
        std::string i2c_bus   = this->get_parameter("i2c_bus")  .as_string();
        int address           = this->get_parameter("address")  .as_int();
        std::string reset_pin = this->get_parameter("reset_pin").as_string();

        auto gpio_write = [&](const std::string& path, const std::string& val) {
            std::ofstream write_file(path);
            if (write_file.is_open()) {
                write_file << val;
            }
        };

        RCLCPP_INFO(get_logger(), "IMUBNO055Node():setup_hardware(): " 
                                  "resetting sensor on GPIO %s...", reset_pin.c_str());
        std::string gpio_base = "/sys/class/gpio/gpio" + reset_pin;
        if (std::filesystem::exists(gpio_base) ==  false) {
            std::ofstream export_file("/sys/class/gpio/export");
            if (export_file.is_open()) {
                export_file << reset_pin;
                export_file.close();
            }
            std::this_thread::sleep_for(std::chrono::milliseconds(300));
        }
        
        gpio_write(gpio_base + "/direction", "out");
        gpio_write(gpio_base + "/value", "0");
        std::this_thread::sleep_for(std::chrono::milliseconds(100));
        gpio_write(gpio_base + "/value", "1");
        std::this_thread::sleep_for(std::chrono::milliseconds(700));

        i2c_fd_ = open(i2c_bus.c_str(), O_RDWR);
        if (i2c_fd_ < 0) {
            RCLCPP_ERROR(get_logger(), "IMUBNO055Node():setup_hardware(): failed to open I2C bus %s",i2c_bus.c_str());
            return false;
        }
        if (ioctl(i2c_fd_, I2C_SLAVE, address) < 0) {
            RCLCPP_ERROR(get_logger(), "IMUBNO055Node():setup_hardware(): "
                                       "Failed to connect to BNO055 at 0x%02x", address);
            return false;
        }

        uint8_t config[2] = {0x3D, 0x0C};
        if (write(i2c_fd_, config, 2) != 2) {
            RCLCPP_ERROR(get_logger(), "IMUBNO055Node():setup_hardware(): failed to set NDOF mode");
            return false;
        }
        return true;
    }

    void read_and_publish() {
        uint8_t reg = 0x08;
        uint8_t data[44]; 

        if ((write(i2c_fd_, &reg, 1) != 1) || (read(i2c_fd_, data, 44) != 44)) {
            RCLCPP_WARN_THROTTLE(get_logger(), *get_clock(), 1000, "IMUBNO055Node():read_and_publish():"
                                                                   "I2C Burst Read Failed");
            return;
        }

        auto imu_msg = sensor_msgs::msg::Imu();
        imu_msg.header.stamp = this->get_clock()->now();
        imu_msg.header.frame_id = "imu_link";

        // linear acceleration in m/s^2
        imu_msg.linear_acceleration.x = static_cast<int16_t>(data[33] << 8 | data[32]) / 100.0;
        imu_msg.linear_acceleration.y = static_cast<int16_t>(data[35] << 8 | data[34]) / 100.0;
        imu_msg.linear_acceleration.z = static_cast<int16_t>(data[37] << 8 | data[36]) / 100.0;

        // angular velocity in rad/s
        double dps_to_rads = M_PI / 180.0;
        imu_msg.angular_velocity.x = (static_cast<int16_t>(data[13] << 8 | data[12]) / 16.0) * dps_to_rads;
        imu_msg.angular_velocity.y = (static_cast<int16_t>(data[15] << 8 | data[14]) / 16.0) * dps_to_rads;
        imu_msg.angular_velocity.z = (static_cast<int16_t>(data[17] << 8 | data[16]) / 16.0) * dps_to_rads;

        // orientation quaternion 
        double q_scale = 1.0 / 16384.0; // 2^14
        imu_msg.orientation.w = static_cast<int16_t>(data[25] << 8 | data[24]) * q_scale;
        imu_msg.orientation.x = static_cast<int16_t>(data[27] << 8 | data[26]) * q_scale;
        imu_msg.orientation.y = static_cast<int16_t>(data[29] << 8 | data[28]) * q_scale;
        imu_msg.orientation.z = static_cast<int16_t>(data[31] << 8 | data[30]) * q_scale;

        // euler angles (reg 0x1A-0x1F) 
        auto euler_msg = geometry_msgs::msg::Vector3();
        euler_msg.x = static_cast<int16_t>(data[21] << 8 | data[20]) / 16.0; // roll
        euler_msg.y = static_cast<int16_t>(data[23] << 8 | data[22]) / 16.0; // pitch
        euler_msg.z = static_cast<int16_t>(data[19] << 8 | data[18]) / 16.0; // heading

        imu_pub_->publish(imu_msg);
        euler_pub_->publish(euler_msg);
    }

    int i2c_fd_ = -1;
    rclcpp::Publisher<sensor_msgs::msg::Imu>::SharedPtr       imu_pub_;
    rclcpp::Publisher<geometry_msgs::msg::Vector3>::SharedPtr euler_pub_;
    rclcpp::TimerBase::SharedPtr                              timer_;
};

//////////////////////////////////////////////////////////////////////////////////////////////////////////////////////
int main(int argc, char **argv) {
    rclcpp::init(argc, argv);
    auto node = std::make_shared<IMUBNO055Node>();
    rclcpp::spin(node);
    rclcpp::shutdown();
    return 0;
}

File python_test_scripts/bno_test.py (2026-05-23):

import time
import board
import busio
import digitalio
import adafruit_bno055

def main():
    i2c = busio.I2C(board.SCL, board.SDA)

    bno_reset = digitalio.DigitalInOut(board.D17)
    bno_reset.direction = digitalio.Direction.OUTPUT
    bno_reset.value = False
    time.sleep(0.1)
    bno_reset.value = True 
    time.sleep(0.7)

    sensor = adafruit_bno055.BNO055_I2C(i2c)
    print("Connection established! Reading IMU data... (Ctrl+C to exit)")
    while True:
        heading, roll, pitch = sensor.euler
        print(f"Heading: {heading:6.2f}° | Roll: {roll:6.2f}° | Pitch: {pitch:6.2f}°", end="\r")
        time.sleep(0.2)

if __name__ == "__main__": main()

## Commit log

2026-05-27 - some quick corrections, imu node now runs with the robot
2026-05-29 - adding publisher to rasp pi power voltage
2026-05-29 - add servo voltages to publisher as well
    [cubic_doggo.ros2_control.xacro]
2026-05-29 - power voltage readout not allow by RaspPi 5 - servo voltage publisher not supported by joint_state
    [cubic_doggo.ros2_control.xacro]
2026-06-06 - initial PID function for IMU
2026-06-07 - change initial condition for better CM - the imu code now compiles
2026-06-07 - seems to be reacting, but need to turn the PID
2026-06-09 - PID tests
2026-06-09 - using ros2_control's PID function instead: control_toolbox/pid.hpp
2026-06-13 - using Present_Load instead of Present_Current for effort read out - initial imu bno055 read out from ros2_control hardware interface sensor
    [cubic_doggo.ros2_control.xacro, cubic_doggo_controllers.yaml]
2026-06-13 - now compiles
    [cubic_doggo.ros2_control.xacro]
2026-06-13 - some corrections for imu, including correct read out for Present_load (need int16_t) and adding shift options for pitch and roll
2026-06-14 - moving imu readout to from ros2_control
    [cubic_doggo_controllers.yaml]
2026-06-14 - the cubic_doggo_lifecycle_imuController.cpp now runs, and need a new plotJuggler config to monitor
    [cubic_doggo_controllers.yaml]
2026-06-14 - quick update so rasp_pi_peripheral_node.cpp print out paths if no found
2026-06-15 - corrected the imu not reading problem in src/my_robot_commander/src/cubic_doggo_lifecycle_imuController.cpp - update the plotjuggler to present euler angles in degree
    [cubic_doggo_controllers.yaml]
2026-06-16 - correct the IMU correction directions
2026-06-17 - still fighting for PID with IMU yet get enough time for moveit to process
2026-06-20 - update to fight for the IMU PID. Adding an indepedent kD correction with smoothing to fight drastic gitters. Still too much oscillation at the moment
2026-06-20 - adding the CAD model after all
    [XL430holderBasic.FCStd, XL430holderBasic.stl, XL430holderThighBack.FCStd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]
2026-06-21 - adding a much better compliant feet design - adding also the corresponding Cura configs
    [calfFeetSpring.FCStd]
2026-06-21 - applying fast/slow alpha, using the slow one for kD rate evaluation
    [cubic_doggo.urdf.xacro, cubic_doggo_legB.xacro, cubic_doggo_legF.xacro]
2026-06-21 - using angular velocity directly for kD, still seems have lag? Will tune PID one last day
2026-06-22 - updated sync the alpha between pitch/roll and their velocity
2026-06-27 - update PID tunning for standing one last time. Something is broken with the walk gait however....
2026-06-27 - adding cubic_doggo_lifecycle_imuController_walking.cpp as the initial code for IMU correction during a walk gait
    [calfFeetSpring.FCStd]
2026-07-04 - some updates in CAD
    [basePlate.FCStd, calfFeet.FCStd, hdmiHolder.FCStd]
2026-07-07 - compile walking with PID
2026-07-15 - update to the spring leg CAD
    [baseTorso.FCStd, calfFeetSpring.FCStd, hdmiHolder.FCStd]
2026-07-18 - walking with IMU works code-wise
2026-07-19 - calfFeetSpring to avoid collision - XL430holderThigh to avoid ~0.5mm gap - baseTorso.FCStd to allow other IMU installation
    [XL430holderThighBack.FCStd, XL430holderThighFront.FCStd, baseTorso.FCStd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]
2026-07-21 - final tunning for walking with IMU using BNO055
2026-07-25 - adding calfFeetSpring.stl
    [calfFeetSpring.stl]
2026-07-25 - added missing .stl files
    [baseTorso.stl, calfJoint.stl]
2026-07-25 - adding more plotJuggler plots
    [cubic_doggo_legB.xacro, cubic_doggo_legF.xacro]
2026-07-25 - updating baseTorso.stl
    [baseTorso.stl]
2026-07-29 - adding toggle for imu
2026-07-29 - tested the toggle for imu, seems to work
